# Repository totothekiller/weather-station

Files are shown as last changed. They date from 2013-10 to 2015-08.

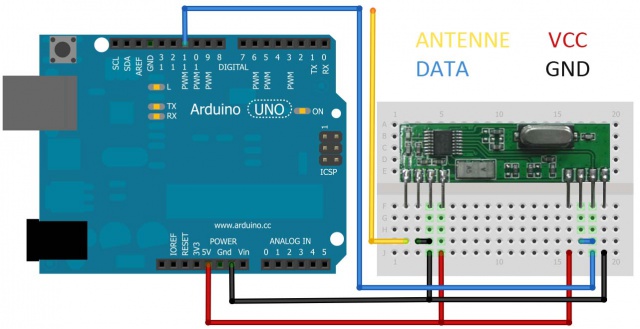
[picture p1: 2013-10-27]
schematics/RX.jpg

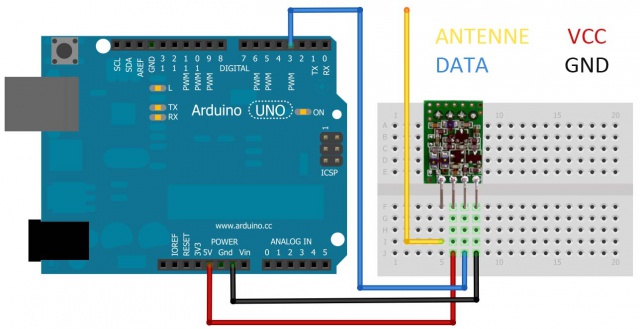
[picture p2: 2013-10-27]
schematics/TX.jpg

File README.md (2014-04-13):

weather-station
===============

An Arduino based Weather Station and more !

Main Station
-------------------------

Parts :
* Arduino Uno Rev 3
* BMP085 (pression + temperature)
* RF receiver 434 MHz
* ENC28J60 Ethernet LAN
* LCD 16x02 display

[Arduino Sketch](MainStation/MainStation.ino)

Remote Temperature Sensors
-------------------------

Parts :
* ATtiny85
* DS18B20 (temperature)
* RF transmitter 434 MHz

[Arduino Sketch](Tx_Node/Tx_Node.ino)

[Schematics](schematic/TX-Node.png)

Folder Structure
-------------------------

| Folder | Description |
| --- | --- |
| **MainStation** | Main Station |
| **Temperature_Node**  | Temperature Sensor |
| hardware | Cores for ATtiny |
| libraries | Libraries for Arduino IDE |
| schematic | Fritzing schematics |
| Test | Tests |

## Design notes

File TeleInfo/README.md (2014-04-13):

Teleinformation
========================

Connection between Arduino / ATtiny85 and electricy meter (EDF compteur type A14C5)

Parts :
* ATtiny85
* Optocoupler SFH620A 
* RF transmitter 434 MHz

[Arduino Sketch](Tx_Node_TeleInfo/Tx_Node_TeleInfo.ino)

Inspiration and original idea from http://www.planet-libre.org/index.php?post_id=11122

EDF Segment structure
------------------------

| Prefix | Description | 
| --- | --- |
| PAPP	 | Instant Power |
| HCHC	 | Compteur Heure Creuse |
| HCHP	 | Compteur Heure Pleine |

Example :
```
__
ADCO 000000000000 B
OPTARIF HC.. <
ISOUSC 30 9
HCHC 003640993 (
HCHP 002633434 ,
PTEC HP..  
IINST 002 Y
IMAX 036 H
PAPP 00460 +
HHPHC A ,
MOTDETAT 000000 B
__
ADCO 000000000000 B
OPTARIF HC.. <
ISOUSC 30 9
HCHC 003640993 (
HCHP 002633434 ,
PTEC HP..  
IINST 002 Y
IMAX 036 H
PAPP 00450 *
HHPHC A ,
MOTDETAT 000000 B
__
ADCO 000000000000 B
OPTARIF HC.. <
ISOUSC 30 9
HCHC 003640993 (
HCHP 002633434 ,
PTEC HP..  
IINST 002 Y
IMAX 036 H
PAPP 00460 +
HHPHC A ,
MOTDETAT 000000 B
__
```

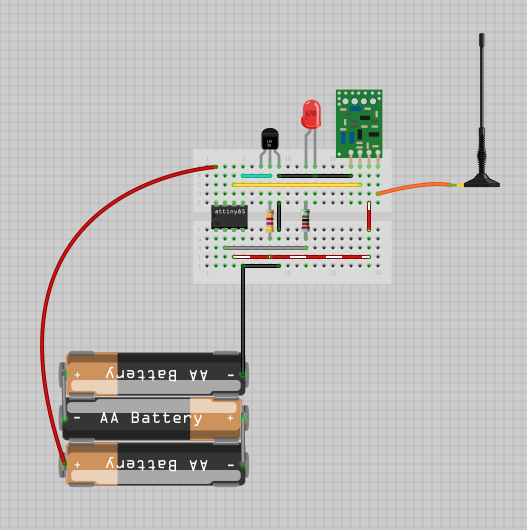
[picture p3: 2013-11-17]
schematics/TX-Node-view.png

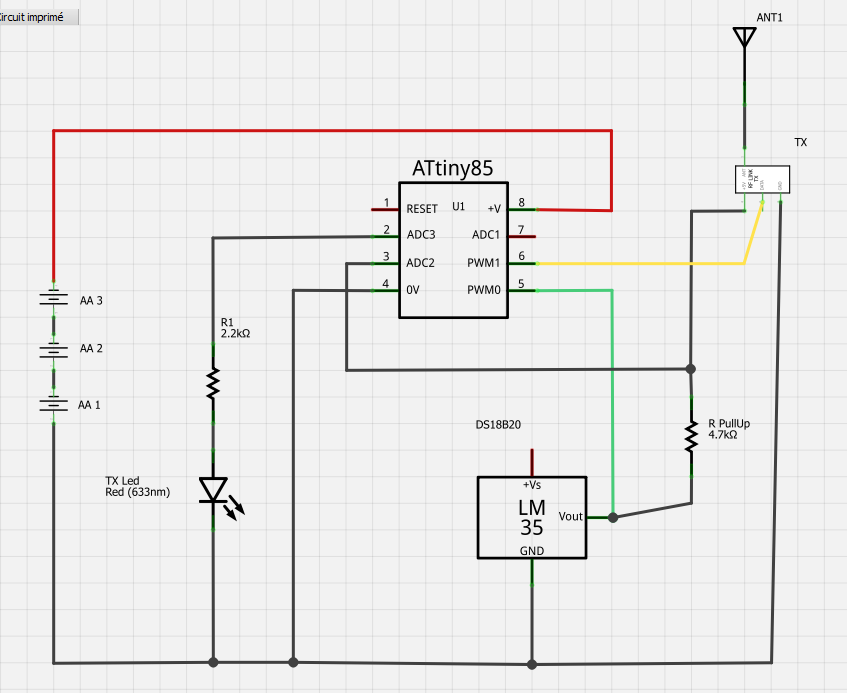
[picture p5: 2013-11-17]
schematics/TX-Node.png

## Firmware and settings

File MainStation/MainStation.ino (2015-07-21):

//
// Display Temp
//

// Use Library from :
// Adafruit BMP085 https://github.com/adafruit/Adafruit_BMP085_Unified
// Adafruit Sensor https://github.com/adafruit/Adafruit_Sensor
// LCD : https://bitbucket.org/fmalpartida/new-liquidcrystal/wiki/Home
// Touch Sensor : https://github.com/arduino-libraries/CapacitiveSensor
// Ethercard : https://github.com/jcw/ethercard

#include <Manchester.h>
#include <Wire.h>
#include <LCD.h>
#include <LiquidCrystal_I2C.h>
#include <CapacitiveSensor.h>
#include <Adafruit_Sensor.h>
#include <Adafruit_BMP085.h>
#include <EtherCard.h>
#include <avr/wdt.h>

// LCD I2C Adress
#define I2C_ADDR 0x27

// LCD Static Config
#define BACKLIGHT_PIN 3
#define En_pin 2
#define Rw_pin 1
#define Rs_pin 0
#define D4_pin 4
#define D5_pin 5
#define D6_pin 6
#define D7_pin 7

#define BACKLIGHT_DURATION 20000

// Pin Configuration
#define rxLed 6
#define rxPin 7
#define touchCommonPin 2
#define touchSensPin 4

// Touch sensibility
#define TOUCH_SENSIBILITY 100

// Contact De-Bouncing
#define TOUCH_DEBOUNCING 250

// Main sensor update
#define MAIN_SENSOR_UPDATE 240000

// Timeout for HTTP Request
#define HTTP_TIMEOUT 2000

// Touched
CapacitiveSensor _touch = CapacitiveSensor(touchCommonPin,touchSensPin); 

// Athmospheric Sensor 
Adafruit_BMP085 _mainSensor = Adafruit_BMP085();

// MAC Address
static const byte _mymac[] = {0x74, 0x69, 0x69, 0x2D, 0x30, 0x31 };

// remote website ip address and port
static const char _website[] PROGMEM = "example.com";

// Remote URL
static const char _baseURL[] PROGMEM = "/riot-server/points/add/";

// Main Ethernet Buffer
byte Ethernet::buffer[600];

// Sensor Defintion
typedef struct SensorStruct {
  char * name; 
  uint8_t id; // Sensor ID
  float value; 
  char * unit; // Unit
} SensorDefinition;

// Rendering
typedef struct RenderStruct {
  LiquidCrystal_I2C lcd; // LCD
  byte  currentSensor; // Current sensor to display
  byte tick; // Used for transition
  volatile bool paint; // paint is in progress ?
} RenderDefinition;

// Sensor RX Data
typedef struct RxSensorDataStruct {
  uint8_t id; // size 1
  float value; // size 4
  uint8_t checksum; // size 1
} RxSensorDataDefinition;

typedef union RxSensorRawDataStruc{
  RxSensorDataDefinition decoded;
  uint8_t raw[6]; // total size of 6 bytes
} RxSensorRawDataDefinition;

// Ethernet Structure
typedef struct EthernetStruct {
  BufferFiller buffer;  // used as cursor while filling the buffer
  char url[15]; // HTTP dynamic URL
  volatile boolean isHttpRequest; // true during HTTP request
} EthernetDefinition;

// Main Application Structure
typedef struct ApplicationStruct {
  byte nbrSensors;
  SensorDefinition sensors[4]; // Sensors Definition
  RenderDefinition render; // LCD rendering
  RxSensorRawDataDefinition rx; // RX receiver
  EthernetDefinition eth; // Ethernet
  unsigned long lastTouched; // Last Touched time
  unsigned long lastMainSensorUpdated; // Last time that the main sensor was updated
} ApplicationDefinition;

// Static Definition
static ApplicationDefinition _app = {
  4, // Total number of sensors
  // Sensors
  {
    // Sensor #0
    {
      "Inside Temp",
      1, // Sensor ID
      -99.0, // Initial Value
      "C"
    },
    // Sensor #1
    {
      "Outside Temp",
      42, // Sensor ID
      -99.0, // Initial Value
      "C"
    },
    // Sensor #2
    {
      "Pressure",
      2, // Sensor ID
      -99.0, // Initial Value
      "hPa"
    },
    // Sensor #3
    {
      "Power",
      5, // Sensor ID
      -99.0, // Initial Value
      "W"
    }
  },
    // Render
  {
    LiquidCrystal_I2C(I2C_ADDR,En_pin,Rw_pin,Rs_pin,D4_pin,D5_pin,D6_pin,D7_pin),
    0,
    0,
    true // force paint
  },
  
  // RX Reveiver
  {
    // Init array with 0
  },
  // omit other fields -> init to 0
};


void setup() {
  //
  // First Activate Watchdog
  wdt_enable(WDTO_8S); // 8 sec
  
  // Led Setup
  pinMode(rxLed, OUTPUT);

  // Debug
  Serial.begin(57600);
  Serial.println(F("--- TTK Weather Station ---"));
  
  // Set Up LCD
  _app.render.lcd.begin (16,2); // 16x2 LCD
  _app.render.lcd.setBacklightPin(BACKLIGHT_PIN,POSITIVE);
  _app.render.lcd.setBacklight(HIGH);
  _app.render.lcd.clear();
  _app.render.lcd.print(F("--- Welcome ---"));
  _app.render.lcd.setCursor(0,1);
  _app.render.lcd.print(F("waiting IP..."));

  // Initialise 
  if(!_mainSensor.begin())
  {
    /* There was a problem detecting the BMP085 ... check your connections */
    Serial.print(F("Ooops, no BMP085 detected ..."));
  }

  // 
  // Setup Ethernet
  if (ether.begin(sizeof Ethernet::buffer, _mymac) == 0)
  {
    Serial.println(F("Failed to access Ethernet controller"));
  }
  
  //
  // Stop WatchDog during DHCP
  wdt_disable();
  
  Serial.println(F("Setting up Dynamic IP"));

  if (!ether.dhcpSetup())
  {
    Serial.println(F("DHCP failed"));
  }
  
  ether.printIp(F("IP:  "), ether.myip);
  ether.printIp(F("GW:  "), ether.gwip);  
  ether.printIp(F("DNS: "), ether.dnsip);  

  if (!ether.dnsLookup(_website))
  {
    Serial.println(F("DNS failed"));
  }
  
  ether.printIp(F("SRV: "), ether.hisip);
  
  // No Request Yet
  _app.eth.isHttpRequest = false;
  
  //
  // Re-Activate Watchdog
  wdt_enable(WDTO_8S); // 8 sec
  
  // Set Up RX
  man.setupReceive(rxPin);
  
  // Start Receiving
  man.beginReceiveArray(6, _app.rx.raw);
  
  // Display Free RAM
  displayFreeRam();
}

void loop() {
  
  // Restart Watchdog
  wdt_reset();
  
  // Detech user touch
  detectTouch();

  // Check RX
  checkIncomingData();
  
  // Check Ethernet
  checkEthernet();

  // Update Local Sensor
  updateLocalSensors();

  // Paint
  render();
}


//
// Touched Detection
//
void detectTouch()
{
  // Turn the ligth ?
  long touched =  _touch.capacitiveSensor(30);

  unsigned long currentTime = millis();

  if(touched >= TOUCH_SENSIBILITY && currentTime - _app.lastTouched > TOUCH_DEBOUNCING)
  {
    Serial.print(F("!! Touched !! with sensibility of "));Serial.println(touched);   

    _app.lastTouched = currentTime;

    // Handle Event
    onTouchEvent();
  }
  else if( currentTime - _app.lastTouched > BACKLIGHT_DURATION)
  {
    // Backlight off
    _app.render.lcd.setBacklight(LOW); 
  }
}


//
// Handle touch Event
//
void onTouchEvent()
{
   // Backlight on
    _app.render.lcd.setBacklight(HIGH);

    // Display next sensor
    selectNextSensor();
}


//
// LCD Render function
//
void render()
{
  // TODO annimation ?

  // Paint ?
  if(_app.render.paint)
  {
    Serial.print(F("Repaint sensor #"));Serial.println(_app.render.currentSensor);

    _app.render.lcd.clear();
    _app.render.lcd.print(_app.sensors[_app.render.currentSensor].name);
    _app.render.lcd.setCursor (0,1); // go to start of 2nd line
    _app.render.lcd.print(_app.sensors[_app.render.currentSensor].value);
    _app.render.lcd.print(' ');
    _app.render.lcd.print(_app.sensors[_app.render.currentSensor].unit);

    // End of Paint
   _app.render.paint = false;
  }

  // Increment
  _app.render.tick++; // useless
}

 
//
// Diplay the Next Sensor
//
void selectNextSensor()
{
  // Change current sensor
  _app.render.currentSensor = (_app.render.currentSensor + 1) % _app.nbrSensors;

  Serial.print(F("Select Next Sensor #"));Serial.println(_app.render.currentSensor);

  // Force Repaint
  _app.render.paint = true;
}


//
// Check if we have a unread message in the air
//
void checkIncomingData()
{
  // Message Received ?
  if(man.receiveComplete())
  {
    digitalWrite(rxLed, HIGH);
  
    // DEBUG
    if(Serial)
    {
      Serial.print(F("RX incomming data : "));
  
      // HEX DUMP
      for (int i = 0; i < 6; i++)
      {
        Serial.print(_app.rx.raw[i], HEX);
      }
      Serial.println("");
    }
  
    // Checksum Validation
    uint8_t checksum = crc8(_app.rx.raw,6);
    
    if(checksum==0)
    {
      // Fire this new value        
      fireNewSensorValue(_app.rx.decoded.id, _app.rx.decoded.value);
    } 
    else
    {
     // DEBUG
      if(Serial)
      {
        Serial.print(F("Bad CheckSum :"));
        Serial.println(checksum, HEX);
      }
  
      // Try to restart RX module
      man.stopReceive();
      delay(1000);
      man.setupReceive(rxPin);   
    }
    
    // Prepare Next Receiving
    man.beginReceiveArray(6, _app.rx.raw);
    
    digitalWrite(rxLed, LOW);
   }
   else
   {
    // If no message found
   
    // After some time
    // reset then restart reveiving 
    
    //Serial.print(F("RF State = "));Serial.println(rx_mode);
   }
}


void fireNewSensorValue(byte sensorID, float newValue)
{
  Serial.print(F("Sensor ID = "));Serial.print(sensorID);
  Serial.print(F(", new value = "));Serial.println(newValue);

  // Find in the sensor the SensorDefinition
  for (int i = 0; i < (_app.nbrSensors); ++i)
  {
    if(_app.sensors[i].id==sensorID)
    {
      Serial.print(F(" -> sensor is #"));Serial.println(i);

      // Update value
      _app.sensors[i].value = newValue;

      // Repaint if we display the current value
      if(i==_app.render.currentSensor)
      {
        _app.render.paint = true;
        Serial.println(F(" -> Repaint is requested"));
      }

      break; // Exit loop
    }
  }
  
  //
  // Send value to Web Server
  sendDataToWebServer(sensorID, newValue);
}


//
// Update Local sensors
//
static void updateLocalSensors()
{
  // Get time
  unsigned long currentTime = millis();

  // Check if we have to update the main sensor
  if(currentTime - _app.lastMainSensorUpdated > MAIN_SENSOR_UPDATE)
  {
    Serial.println(F("Update Local Sensor"));

    _app.lastMainSensorUpdated = currentTime;

    // Read Temp sensor
    float temp = _mainSensor.readTemperature();

    // Notify new Value
    fireNewSensorValue(1, temp);

    // Read Pressure sensor (in Pa)
    float pressure = (float) _mainSensor.readPressure();

    // Notify new Value (in hPa)
    fireNewSensorValue(2, pressure/100.0);
  }
}


//
// Check Ethernet bus
//
void checkEthernet()
{
  // check if anything has come in via ethernet
  word len = ether.packetReceive();
  word pos = ether.packetLoop(len);
}


//
// Send Data to WebServer : sensorID/newValue
//
void sendDataToWebServer(byte sensorID, float newValue)
{
  // Convert to String
  sprintf(_app.eth.url, "%d/", sensorID);

  // Convert Float to String
  char newValueString[10];
  dtostrf(newValue, 2, 2, newValueString);
  
  // Concat
  strcat(_app.eth.url,newValueString);
  
  Serial.print(F(">>> HTTP Request : "));Serial.println(_app.eth.url);
  
  // Init Request
  _app.eth.isHttpRequest = true;
  const unsigned long dateHTTPrequest = millis();
  
  // Send Request  
  ether.browseUrl(_baseURL, _app.eth.url, _website, requestUrlCallback);  
  
  //
  // Wait end of HTTP Request
  while(millis() - dateHTTPrequest < HTTP_TIMEOUT && _app.eth.isHttpRequest )
  {
    ether.packetLoop(ether.packetReceive());
  }
   
  // Verify
  if(_app.eth.isHttpRequest)
  {
    Serial.println(F("Fail Of HTTP Request !"));
     
    // Reset Flag
    _app.eth.isHttpRequest = false;
  }
  
  // Workaround to clean Ethernet ...
  const unsigned long dateHTTPend = millis();
  while(millis() - dateHTTPend < HTTP_TIMEOUT)
  {
    ether.packetLoop(ether.packetReceive());
  }
}

// 
// End HTTP GET request Callback
//
static void requestUrlCallback (byte status, word off, word len) {
  Serial.println(F("<<< RESPONSE :"));
  
  // Set end of String (for correct display in println)
  Ethernet::buffer[min(599, off + len)] = 0;
  
  // Display response
  Serial.println((const char*) Ethernet::buffer + off);
  
  // Turn off HTTP request flag
  _app.eth.isHttpRequest = false; 
}


//
// Get the Free RAM
static int freeRam () {
  extern int __heap_start, *__brkval; 
  int v; 
  return (int) &v - (__brkval == 0 ? (int) &__heap_start : (int) __brkval); 
}

//
// Display to Serial the available RAM memory
void displayFreeRam()
{
  Serial.print(F("Free Ram = "));Serial.println(freeRam());
}

// This table comes from Dallas sample code where it is freely reusable,
// though Copyright (C) 2000 Dallas Semiconductor Corporation
static const uint8_t PROGMEM dscrc_table[] = {
      0, 94,188,226, 97, 63,221,131,194,156,126, 32,163,253, 31, 65,
    157,195, 33,127,252,162, 64, 30, 95,  1,227,189, 62, 96,130,220,
     35,125,159,193, 66, 28,254,160,225,191, 93,  3,128,222, 60, 98,
    190,224,  2, 92,223,129, 99, 61,124, 34,192,158, 29, 67,161,255,
     70, 24,250,164, 39,121,155,197,132,218, 56,102,229,187, 89,  7,
    219,133,103, 57,186,228,  6, 88, 25, 71,165,251,120, 38,196,154,
    101, 59,217,135,  4, 90,184,230,167,249, 27, 69,198,152,122, 36,
    248,166, 68, 26,153,199, 37,123, 58,100,134,216, 91,  5,231,185,
    140,210, 48,110,237,179, 81, 15, 78, 16,242,172, 47,113,147,205,
     17, 79,173,243,112, 46,204,146,211,141,111, 49,178,236, 14, 80,
    175,241, 19, 77,206,144,114, 44,109, 51,209,143, 12, 82,176,238,
     50,108,142,208, 83, 13,239,177,240,174, 76, 18,145,207, 45,115,
    202,148,118, 40,171,245, 23, 73,  8, 86,180,234,105, 55,213,139,
     87,  9,235,181, 54,104,138,212,149,203, 41,119,244,170, 72, 22,
    233,183, 85, 11,136,214, 52,106, 43,117,151,201, 74, 20,246,168,
    116, 42,200,150, 21, 75,169,247,182,232, 10, 84,215,137,107, 53};

//
// Compute a Dallas Semiconductor 8 bit CRC. These show up in the ROM
// and the registers.  (note: this might better be done without to
// table, it would probably be smaller and certainly fast enough
// compared to all those delayMicrosecond() calls.  But I got
// confused, so I use this table from the examples.)
//
uint8_t crc8(const uint8_t *addr, uint8_t len)
{
	uint8_t crc = 0;

	while (len--) {
		crc = pgm_read_byte(dscrc_table + (crc ^ *addr++));
	}
	return crc;
}

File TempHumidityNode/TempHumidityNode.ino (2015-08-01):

//
// TX Node with Temperature + Humidity
//
// Based on Sensor AM2302 (DHT22) http://snootlab.com/adafruit/252-capteur-de-temperature-et-humidite-am2302.html

#include <Manchester.h>
#include <DHT.h>
#include <avr/wdt.h>
#include <avr/power.h>
#include <avr/interrupt.h>
#include <avr/sleep.h>


#define DHTTYPE DHT22   // DHT 22  (AM2302)

#define sensID_Temp 10  // Sensor ID for Temp
#define sensID_Humid 11 // Sensor ID for Humidity

#if defined(__AVR_ATtiny85__) // ATtiny85 mode
#define ECO // Low Power Mode

#define txLed 3  // TX LED
#define txPin 1  // TX Out
#define sensPin 0  // Sensor Pin
#define powerPin 4 // Power line for Tx module and sensor

#else
#define DEBUG  // Is serial debug active ?

#define txLed 13  // TX LED
#define txPin 12  // TX Out
#define sensPin 2  // Sensor Pin
#define powerPin 8 // Power line for Tx module and sensor
#endif

#define WATCHDOG_TIMER WDTO_8S // 8 sec
#define SLEEP_LOOP  4 // Deep Sleep total time = WATCHDOG_TIMER * SLEEP_LOOP

// Sensor Message Structure
typedef struct sensorData_t{
  uint8_t id; // size 1
  float value; // size 4
  uint8_t checksum; // size 1
};

typedef union sensorData_union_t{
  sensorData_t data;
  uint8_t raw[6]; // total size of 6 bytes
};

// Sensor Message
sensorData_union_t _message; 

// WatchDof Counter
volatile byte _watchdogCounter;

// WatchDog interruption
ISR(WDT_vect) {
  _watchdogCounter++;
}


// Toggle flag : if true => Aquire Temp, if false => Acquire Humidity
boolean _flag = true;

// Initialize DHT sensor for normal 16mhz Arduino
DHT dht(sensPin, DHTTYPE);

void setup() {
    // Debug
  #ifdef DEBUG
    Serial.begin(9600);
    Serial.println("--- SETUP ---");
  #endif

}

void loop()
{
  // Power On !
  powerUp();

  // Turn LED On
  digitalWrite(txLed, HIGH);

  // Read Temp
  if (_flag && acquireTemp())
  {
    // Send !
    fireNewValueEvent();
  }
 
  // Read Humidity
  if (!_flag && acquireHumidity())
  {
    // Send !
    fireNewValueEvent();
  }

  // sets the LED off
  digitalWrite(txLed, LOW);

  // Toggle flag
  toggleFlag();

  // Power Off
  powerDown();

  // Go to Sleep Mode Zzzzz
  deepSleep();
}

// 
// Power Up Tx Module and sensor
// Turn txLed ON
void powerUp()
{
  // Power On
  pinMode(powerPin, OUTPUT);
  digitalWrite(powerPin,HIGH);

  // Led Setup
  pinMode(txLed, OUTPUT);
  
  delay(500);
  
  // DHT Startup
  dht.begin();

  delay(500);
}

//
// Shut down power line
void powerDown()
{
  // Power Down
  digitalWrite(powerPin,LOW);

  // Set all pin in INPUT mode
  pinMode(powerPin, INPUT);
  pinMode(txLed, INPUT);
  pinMode(txPin, INPUT);
  pinMode(sensPin,INPUT);
}

/*
 * Read Temp
 */
boolean acquireTemp()
{
  // Read temperature as Celsius
  float t = dht.readTemperature();
  
  if (isnan(t)){
#ifdef DEBUG
    Serial.println("Failed to read Temp from DHT sensor!");
#endif
    return false;
  }
  
  // Write Sensor ID
  _message.data.id = sensID_Temp;
  
  // Save temperature
  _message.data.value = t;
  
  return true;
}
/*
 * Read Humidity
 */
boolean acquireHumidity()
{
  // Reading temperature or humidity takes about 250 milliseconds!
  float h = dht.readHumidity();
   
  if (isnan(h)){
#ifdef DEBUG
    Serial.println("Failed to read Humidity from DHT sensor!");
#endif
    return false;
  }
  
  // Write Sensor ID
  _message.data.id = sensID_Humid;
  
  // Save Humidity
  _message.data.value = h;
  
  return true; 
}

//
// Send New Sensor Value
//
void fireNewValueEvent()
{
  // Restart Watchdog
  //wdt_reset();
  
  // Compute Checksum : CRC8 on ID+Value (Checksum is computed on the first 5 bytes)
  _message.data.checksum = crc8(_message.raw, 5);

#ifdef DEBUG
    Serial.print("Sensor="); 
    Serial.print(_message.data.id); 
    Serial.print(", Value="); 
    Serial.print(_message.data.value);
    Serial.print(", CheckSum=0x"); 
    Serial.println(_message.data.checksum, HEX);
#endif

  // TX Setup
  man.setupTransmit(txPin);
  
  // Send All Data
  man.transmitArray(6, _message.raw);
}


//
// Toggle Boolean Flag
//
void toggleFlag()
{
  if (_flag)
  {
    _flag = false;
  }
  else
  {
    _flag = true;
  }
}

//
// Put ATtiny85 in deep sleep mode 
//
// Power is reduce to :
//    - ~7µA BOD disabled
//    - ~30µA BOD enabled
//
void deepSleep()
{
#ifndef ECO
  delay(120000); // 2 min sleep
#else
  
  //
  // Prepare for shutdown
  
  bitClear(ADCSRA,ADEN); //Disable ADC
  //bitSet(PRR,PRADC); not working...
  //power_adc_disable(); not working...

  ACSR = (1<<ACD); //Disable the analog comparator
  DIDR0 = 0x3F; //Disable digital input buffers on all ADC0-ADC5 pins

  PRR = 0x0F; //Reduce all power right before sleep
  
  
  //
  // Start Watchdog
  setup_watchdog(WATCHDOG_TIMER);
  
  //
  // Prepare for Sleep
  
  while(_watchdogCounter<SLEEP_LOOP){
  
  set_sleep_mode(SLEEP_MODE_PWR_DOWN); // sleep mode
  
  noInterrupts();
  sleep_enable();
  // Disable BOD : my ATtiny85 doesn't have this fonctionality ...
  interrupts();
  
  
  sleep_cpu();                   // System sleeps here
  sleep_disable();               // System continues execution here when watchdog timed out 
  
  } 
  
  //
  // Stop WatchDog
  setup_watchdog(-1);
  
  // Restore Power
  PRR = 0x00; //Restore power reduction
  DIDR0 = 0x00; //Restore digital input buffers on all ADC0-ADC5 pins
#endif
}

#ifdef ECO

//
// Watchdog setup
// From https://github.com/jcw/jeelib/blob/master/Ports.cpp
// 
void setup_watchdog(char mode) {

  // correct for the fact that WDP3 is *not* in bit position 3!
  if (mode & bit(3))
  { 
    mode ^= bit(3) | bit(WDP3);
  }
  // pre-calculate the WDTCSR value, can't do it inside the timed sequence
  // we only generate interrupts, no reset
  byte wdtcsr = mode >= 0 ? bit(WDIE) | mode : 0;
  
  MCUSR &= ~(1<<WDRF);

  noInterrupts();

  WDTCR |= (1<<WDCE) | (1<<WDE); // timed sequence
  WDTCR = wdtcsr;
  
  // Reset counter
   _watchdogCounter=0;
  
  interrupts();
}

#endif
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

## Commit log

2013-10-27 Add Read Temp + create ReadTemp Library
    [weather-station-schematic.fzz]
2013-10-29 Add arduino-tiny Core
    attiny core from
    https://code.google.com/p/arduino-tiny/
2013-10-29 Add blink test for Attiny85
    test OK with new core arduino-tiny
2013-11-04 Scanner I2C
2013-11-08 Add pressure sensor
    + WIP on finite state machine
2013-11-12 Refactor TX side
    -> Remove ReadTempLib
    -> support for ATtiny and Uno
    Use PCREL Patch for WinAVR from :
    - http://forum.arduino.cc/index.php?topic=168510.0
    - https://github.com/TCWORLD/ATTinyCore/tree/master/PCREL%20Patch%20for%20GCC
2013-11-13 Try to save power
    Normal ~7mA
    During sleep ~0.35mA
2013-11-16 Add TX node shematics
    [weather-station-schematic.fzz]
2013-11-16 Create Rx-Node remote sensor
2013-11-17 Solve low power issue with OneWire
    [Tx_Node.ino]
2013-11-17 Shematics update
    [weather-station-schematic.fzz]
2013-12-12 Display and RX receive is working !!
    -> LCD dynamic display
    -> inside temp + pressure
    -> wireless outside temp
2013-12-13 Send value through Ethernet for RIOT-SERVER
    + try to reduce the RAM footprint
    + use flash memory for static message
    + serve a single welcome HTTP page
2014-01-12 Acquire Apparent Power
2014-01-12 Add Link TimeOut + power on/off
2014-04-13 Teleinfo Node is working at low power !
2014-04-16 Add PCB for TeleInfo Node
    [TeleInfo_Node_PCB.fzz]
2014-04-16 Move schematics folder
    [weather-station-schematic.fzz]
2014-11-08 Import Capacitive Sensor library
    from https://github.com/arduino-libraries/CapacitiveSensor.git
2015-01-18 Last update for Teleinfo node schematics
    [TeleInfo_Node_PCB.fzz]
2015-07-19 Update DHT sensor library
2015-07-19 Add Adafruit Sensor Library
2015-07-24 Update ATtiny Core from https://code.google.com/p/arduino-tiny/
2015-07-24 Workaround for ATtiny on Arduino IDE 1.6
    Sources
    http://forum.arduino.cc/index.php?topic=302080.0
    http://forum.arduino.cc/index.php?topic=299759.msg2092740#msg2092740
2015-07-24 Add Watchdog timer
2016-02-08 Add Low Power library
